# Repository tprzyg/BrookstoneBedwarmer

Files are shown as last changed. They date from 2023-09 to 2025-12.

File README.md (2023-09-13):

# Brookstone Bedwarmer / Heated Mattress Pad Controller.

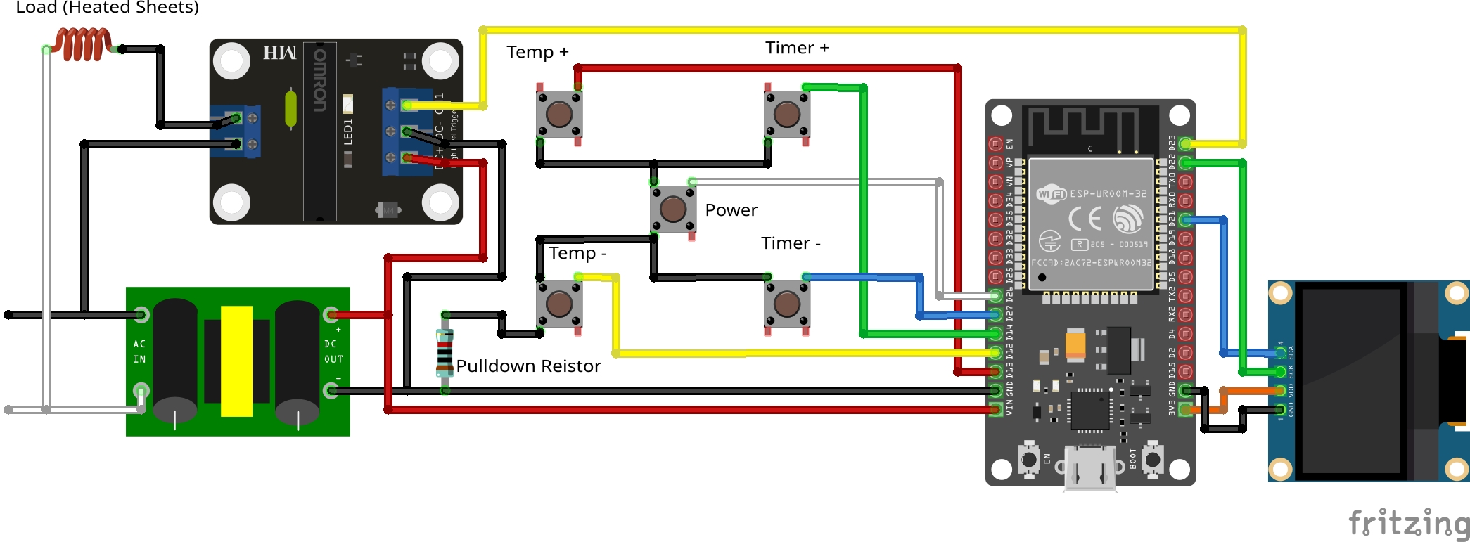
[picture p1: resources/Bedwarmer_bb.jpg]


This was a project to replace a flaky controller for a Brookstone Bedwarmer / Heated Mattress Pad, purchased at Bed Bath and Beyond. The heated mattress pad worked well in the beginning in the US, but after moving to Japan it became very flaky (most likely not liking 100V/50Hz instead of 110V/60Hz).

I used ESP32 board with 0.96" OLED SSD1306 type display, a set of two solid state relays (for controlling the A/C power), a small 5V PSU board and a 2A fuse with a housing. Below are links to the products on Japanese Amazon site (I'm sure that some similar/comparable products exist on your local Amazon or at some local electronics parts store).
- ESP32 DevKit boards: https://amzn.asia/d/9b7Ar7T
- 5V power modules: https://amzn.asia/d/gfirg1F
- Glass tube fuses and inline housings: https://amzn.asia/d/3iPEoGX
- Solid State Relays: https://amzn.asia/d/8DtwuSe
- 0.96" OLED Displays: https://amzn.asia/d/c7P6Bzr

This project could work with some modifications using ESP8266 board as well (I just happened to have extra ESP32 and no ESP8266 on hand).

Wiring the OLED screen is using I2C specific pins on ESP32 as SDA (GPIO_21) and SCL (GPIO_22) - these will be different when using ESP8266!
Also, the OLED screen uses 3.3V, so it is wired to the 3.3V output on ESP32 rather than using separate 3.3V regulator board.
I reused housing and most of the board of the original Brookstone controller (but desoldered most of the components - leaving only buttons/switches on the board).
I masked the display window with black electrical tape (as the 0.96" OLED is slightly smaller than the original segmented LCD - about2mm (about 0.08 in) on each side of the screen is masked). The OLED is (unprofessionally) mounted to the housing with the same black electrical tape. I also used copious amounts of electrical tape to cover the original board, to prevent any prospects of something touching PCB and shorting.
I checked carefully which wire brings "live" A/C and which is neutral and connected the bedwarmer heating element with a fuse on that line, to make sure that if anything electrical malfunction happens there is no "live" current in the bedwarmer / mattress pad.
I also slightly changed the behavior of the controller. The original controller default timer setting was 10hrs with adjustments by 30min up/down and the timer restarted every timer the timer+ or timer- buttons were pressed. My implementation uses a default 3 hrs. timer and with timer+/timer- you can increase or decrease the runtime in 10min steps, without restarting the timer.
The display also shows the remaining time on the timer, rather than the timer setting.

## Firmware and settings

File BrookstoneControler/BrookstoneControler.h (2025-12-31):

#define MIN_TEMP 1
#define MAX_TEMP 99
#define TEMP_STEP 1
#define DEFAULT_TEMP 25
#define MIN_DUTY_CYCLE 0
#define MAX_DUTY_CYCLE 1
#define HEATER_TIME_CYCLE 2000

#define TIMER_STEP 1
#define MIN_TIMER TIMER_STEP
#define MAX_TIMER 720
#define DEFAULT_TIMER 180

#define MIN_DELAY_TIME 180
#define MIN_BUTTON_PRESS_TIME 200

// Define PINs for buttons,
#define TEMP_PLUS_PIN GPIO_NUM_13
#define TEMP_MINUS_PIN GPIO_NUM_12
#define TIMER_PLUS_PIN GPIO_NUM_14
#define TIMER_MINUS_PIN GPIO_NUM_27
#define POWER_ON_PIN GPIO_NUM_26
#define HEATER_RELAY_PIN GPIO_NUM_25

// Settings for the 0.96" SSD1306 OLED SCREEN
#define SCREEN_I2C 0x3C
#define SCREEN_WIDTH 128
#define SCREEN_HEIGHT 64
#define DISPLAY_DIMMING 15000
#define DISPLAY_TIMEOUT 60000
#define DISPLAY_REFRESH_RATE 500

#define DEBUG_LEVEL 1

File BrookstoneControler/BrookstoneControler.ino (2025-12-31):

/*
 * Brookstone Bedwarmer replacement controller.
 * (C)2022 Tomasz Przygoda <tprzyg@yahoo.com>
 *
 * 4 input buttons (reused from the original controller board) for temp+, temp-, timer+ and timer-
 * 1 Power on/off button (also reused from the original board) with display ON it will set the ESP32 into deep sleep
 * The original segmented LCD display was replaced with 0.96" OLED (SSD1306)
 * Temperature is adjusted from 10% to 100% with 10% increments
 * Timer can be adjusted from 1min to 12hrs (originally was from 30min to 8hrs)
 * Logic was changed to allow for 1min timer-step value (originally 30min step value)
 * and also the display will show not the preset timer value, but rather the remaining hours:minutes
 * Display will dim after 15 seconds and go blank after 60 seconds of inactivity
 * When display is inactive, pressing any button (including power button) will reactivate the display
 * When display is active pressing adjustment buttons will make the desired adjustment
 * while pressing power button will turn off heat, reset timer and put the controller into deep sleep
 * When controller is in deep sleep mode, pressing power button will restart and re-initialize the controller,
 * but all other buttons are ignored
 * When timer runs out, the controller will turn off heat, reset timer and put the controller into deep sleep
 */

#include <Wire.h>
#include <Adafruit_GFX.h>
#include <Adafruit_SSD1306.h>
#include <Fonts/FreeSans9pt7b.h>
#include <Fonts/FreeSans12pt7b.h>
#include <Fonts/FreeSans18pt7b.h>
#include <Fonts/FreeSans24pt7b.h>
#include <Fonts/FreeSansBold9pt7b.h>
#include <Fonts/FreeSansBold12pt7b.h>
#include <Fonts/FreeSansBold18pt7b.h>
#include <Fonts/FreeSansBold24pt7b.h>

#include "BrookstoneControler.h"
#include "Button.h"

// Allocate the SSD1306 OLED Screen
Adafruit_SSD1306 display(SCREEN_WIDTH, SCREEN_HEIGHT, &Wire, -1);


bool wifiOn;
bool timerOn;
bool heaterOn;
bool displayOn;
bool refreshDisplay;
bool enterSleepMode;

unsigned int heatSetting;
unsigned int lastButtonPressed;

unsigned long currentTime;
unsigned long timerEndTime = 0;
unsigned long timerStartTime = 0;
unsigned long timerRemaining = 0;

unsigned long lastDisplayOn = 0;
unsigned long lastDisplayUpdateTime = 0;

unsigned long currentPressTime = 0;
unsigned long lastButtonPressTime = 0;
unsigned long lastButtonActionTime = 0;

unsigned long lastHeatOnTime = 0;
unsigned long lastHeatOffTime = 0;

typedef void (*dummyFunction)(void);

void updateHeatSetting(unsigned int myFactor) {
  currentPressTime = millis();
  refreshDisplay = true;
  unsigned int newHeatSetting = heatSetting + TEMP_STEP * myFactor;

  if ((newHeatSetting <= MAX_TEMP) and (newHeatSetting >= MIN_TEMP)) {
    heatSetting = newHeatSetting;
    lastButtonActionTime = currentPressTime;
  }
}

void updateTimerSetting(unsigned int myFactor) {
  currentPressTime = millis();
  refreshDisplay = true;
  unsigned long newTimerEndTime = timerEndTime + (TIMER_STEP * myFactor) * 60000;

  if (((newTimerEndTime - currentTime )<= MAX_TIMER * 60000) and ((newTimerEndTime - currentTime) >= MIN_TIMER * 60000)) {
    timerEndTime = newTimerEndTime;
    lastButtonActionTime = currentPressTime;
  }
}

void IRAM_ATTR temp_up_ISR() {
  currentPressTime = millis();
  if (currentPressTime - lastButtonPressTime > MIN_BUTTON_PRESS_TIME) {
    lastButtonPressTime = currentPressTime;
    if (displayOn) {
      lastButtonPressed = TEMP_PLUS_PIN;
    } else {
      displayOn = true;
      lastDisplayOn = currentPressTime;
    }
  }
}

void IRAM_ATTR temp_down_ISR() {
  currentPressTime = millis();
  if (currentPressTime - lastButtonPressTime > MIN_BUTTON_PRESS_TIME) {
    lastButtonPressTime = currentPressTime;
    if (displayOn) {
      lastButtonPressed = TEMP_MINUS_PIN;
    } else {
      displayOn = true;
      lastDisplayOn = currentPressTime;
    }
  }
}

void IRAM_ATTR timer_up_ISR() {
  currentPressTime = millis();
  if (currentPressTime - lastButtonPressTime > MIN_BUTTON_PRESS_TIME) {
    lastButtonPressTime = currentPressTime;
    if (displayOn) {
      lastButtonPressed = TIMER_PLUS_PIN;
    } else {
      displayOn = true;
      lastDisplayOn = currentPressTime;
    }
  }
}

void IRAM_ATTR timer_down_ISR() {
  currentPressTime = millis();
  if (currentPressTime - lastButtonPressTime > MIN_BUTTON_PRESS_TIME) {
    lastButtonPressTime = currentPressTime;
    if (displayOn) {
      lastButtonPressed = TIMER_MINUS_PIN;
    } else {
      displayOn = true;
      lastDisplayOn = currentPressTime;
    }
  }
}

void IRAM_ATTR power_button_ISR() {
  currentPressTime = millis();
  if (currentPressTime - lastButtonPressTime > MIN_BUTTON_PRESS_TIME) {
    refreshDisplay = true;
    lastButtonPressTime = currentPressTime;
    if (displayOn) {
      lastButtonPressed = POWER_ON_PIN;
      enterSleepMode = true;
    } else {
      displayOn = true;
      lastDisplayOn = currentPressTime;
    }
  }
}

void checkPowerOff() {
  currentTime = millis();
  if (enterSleepMode) {
    Serial.println("Preparing for DEEP_SLEEP mode...");
    if (digitalRead(HEATER_RELAY_PIN) == HIGH) {
      Serial.print("Turning Heater OFF @ ");
      Serial.println(currentTime);
      digitalWrite(HEATER_RELAY_PIN, LOW);
    }
    Serial.println("Turning timer OFF");
    heatSetting = 0;
    timerEndTime = 0;
    timerStartTime = 0;
    timerRemaining = 0;
    Serial.println("Turning display OFF");
    display.clearDisplay();
    display.display();
    display.ssd1306_command(SSD1306_DISPLAYOFF);
    Serial.print("Setting up RTC_WKAEUP on ");
    Serial.print(POWER_ON_PIN);
    Serial.println(" to become a wakeup button");
    esp_sleep_enable_ext0_wakeup(POWER_ON_PIN, 0);
    Serial.println("Entering DEEP_SLEEP mode.");
    delay(1000);
    esp_deep_sleep_start();
  }
}

void updateDisplay() {
  currentTime = millis();
  if (displayOn) {
    if (currentTime - lastDisplayUpdateTime >= DISPLAY_REFRESH_RATE) {
      refreshDisplay = true;
    }
  }
  if (refreshDisplay) {
    lastDisplayUpdateTime = currentTime;
    int timerHours = timerRemaining / 60;
    int timerMinutes = timerRemaining - timerHours * 60;
    char heatStr[8];
    sprintf(heatStr, "%3d%%", heatSetting);
    char timeStr[8];
    sprintf(timeStr, "%2d:%02d", timerHours, timerMinutes);
    if (currentTime - lastDisplayOn > DISPLAY_DIMMING) {
      displayOn = true;
      // PUT DISPLAY DIMMING CODE HERE
    }
    if (currentTime - lastDisplayOn > DISPLAY_TIMEOUT) {
      displayOn = false;
      display.ssd1306_command(SSD1306_DISPLAYOFF);
    }
    if (displayOn) {
      // MAKE SURE DISPLAY IS ON
      display.ssd1306_command(SSD1306_DISPLAYON);
      display.clearDisplay();
      display.setTextColor(WHITE);
      display.setFont(&FreeSans9pt7b);
      display.setTextSize(1);
      display.setCursor(0, 24);
      display.println("Heat:");
      display.setFont(&FreeSansBold12pt7b);
      display.setTextSize(1);
      display.println(heatStr);
      display.setFont(&FreeSans9pt7b);
      display.setTextSize(1);
      display.setCursor(0, 80);
      display.println("Timer:");
      display.setFont(&FreeSansBold12pt7b);
      display.setTextSize(1);
      display.println(timeStr);
      display.display();
    }
    refreshDisplay = false;
    if (DEBUG_LEVEL > 0) {
      Serial.print("LastDisplayOn = ");
      Serial.print((currentTime-lastDisplayOn)/1000);
      Serial.print("s ago, Heat = ");
      Serial.print(heatStr);
      Serial.print(", Timer = ");
      Serial.println(timeStr);
    }
  }
}

void checkTimerOff() {
  currentTime = millis();
  long timerRemainingMillis = timerEndTime - currentTime;
  if (timerRemainingMillis > 60000) {
    timerRemaining = round(timerRemainingMillis / 60000);
  } else {
    timerRemaining = 0;
    timerOn = false;
  }
  if (!timerOn) {
    timerEndTime = 0;
    timerStartTime = 0;
    timerRemaining = 0;
    timerOn = false;
    heaterOn = false;
    enterSleepMode = true;
  }
}

void runHeater() {
  currentTime = millis();
  if (timerOn) {
    unsigned long dutyOnTime = round(HEATER_TIME_CYCLE * (heatSetting * 0.01 * (MAX_DUTY_CYCLE - MIN_DUTY_CYCLE) + MIN_DUTY_CYCLE));
    unsigned long dutyOffTime = HEATER_TIME_CYCLE - dutyOnTime;
    if ((heatSetting >= MIN_TEMP) and (heatSetting <= MAX_TEMP)) {
      if (!heaterOn) {
        if (currentTime - lastHeatOffTime >= dutyOffTime) {
          // TURN THE HEAT ON
          digitalWrite(HEATER_RELAY_PIN, HIGH);
          if (DEBUG_LEVEL > 0) {
            Serial.print("Heater ON after ");
            Serial.println(currentTime - lastHeatOffTime);
          }
          heaterOn = true;
          lastHeatOnTime = currentTime;
        }
      } else {
        if (currentTime - lastHeatOnTime >= dutyOnTime) {
          // TURN THE HEAT OFF
          digitalWrite(HEATER_RELAY_PIN, LOW);
          if (DEBUG_LEVEL > 0) {
            Serial.print("Heater OFF after ");
            Serial.println(currentTime - lastHeatOnTime);
          }
          heaterOn = false;
          lastHeatOffTime = currentTime;
        }
      }
    } else {
      Serial.println("Invalid heat setting... ignoring...");
      // MAKE SURE THAT THE HEAT IS OFF
      if (digitalRead(HEATER_RELAY_PIN) == HIGH) {
        digitalWrite(HEATER_RELAY_PIN, LOW);
      }
    }
  }
}

void checkButtons() {
  currentTime = millis();
  bool buttonAction = false;
  unsigned int actionFactor = 1;
  if (digitalRead(lastButtonPressed) == LOW) {
    if (currentTime - lastButtonPressTime > 10 * MIN_BUTTON_PRESS_TIME) {
      buttonAction = true;
      actionFactor = 10;
    } else if (currentTime - lastButtonPressTime > 5 * MIN_BUTTON_PRESS_TIME) {
      buttonAction = true;
      actionFactor = 5;
    } else if (currentTime - lastButtonActionTime > MIN_BUTTON_PRESS_TIME) {
      buttonAction = true;
    }
  }
  if (currentTime - lastButtonActionTime < round(2*MIN_BUTTON_PRESS_TIME / actionFactor)) {
    buttonAction = false;
  }
  if (buttonAction) {
    lastButtonActionTime = currentTime;
    switch (lastButtonPressed) {
      case TEMP_PLUS_PIN:
       updateHeatSetting(1);
       break;
      case TEMP_MINUS_PIN:
       updateHeatSetting(-1);
       break;
      case TIMER_PLUS_PIN:
       updateTimerSetting(1);
       break;
      case TIMER_MINUS_PIN:
       updateTimerSetting(-1);
       break;
    }
  }
}

void setup_pin(unsigned int PIN, dummyFunction ISR_routine) {
  pinMode(PIN, INPUT_PULLUP);
  attachInterrupt(PIN, ISR_routine, FALLING);
}

void setup() {
  // Setup Serial Monitor
  Serial.begin(115200);
  // Initialize the SSD1306 OLED Screen
  if (!display.begin(SSD1306_SWITCHCAPVCC, SCREEN_I2C)) {
    Serial.println(F("SSD1306 allocation failed"));
    delay(10000);
    ESP.restart();
  }
  delay(2000);
  display.ssd1306_command(SSD1306_DISPLAYON);
  display.clearDisplay();
  display.setRotation(1);
  display.setTextColor(WHITE);
  display.setFont(&FreeSans9pt7b);
  display.setTextSize(1);
  display.clearDisplay();
  display.display();
  Serial.println("ESP32 Controller for a Brookstone Heated Mattress Pad.");
  timerOn = true;
  heaterOn = false;
  displayOn = true;
  refreshDisplay = true;
  enterSleepMode = false;
  heatSetting = DEFAULT_TEMP;
  lastDisplayOn = currentTime;
  timerStartTime = currentTime;
  timerRemaining = DEFAULT_TIMER;
  timerEndTime = timerStartTime + DEFAULT_TIMER * 60000;
  lastButtonPressTime = currentTime;
  setup_pin(POWER_ON_PIN, power_button_ISR);
  setup_pin(TEMP_PLUS_PIN, temp_up_ISR);
  setup_pin(TEMP_MINUS_PIN, temp_down_ISR);
  setup_pin(TIMER_PLUS_PIN, timer_up_ISR);
  setup_pin(TIMER_MINUS_PIN, timer_down_ISR);
  pinMode(HEATER_RELAY_PIN, OUTPUT);
  display.println("ON");
  display.display();
  updateDisplay();
}

void loop() {
  checkButtons();
  checkTimerOff();
  checkPowerOff();
  updateDisplay();
  runHeater();
}

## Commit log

2022-12-31 adding initial version of the controller sketch - there are some bugs to fix, before fully working
    [BrookstoneControler.ino]
2022-12-31 Update BrookstoneControler.ino
    started to refactor to use timerRemaining minutes rather than the convoluted timerSetting and calculating remaining on the fly (which sometimes ended up with timerRemaining going negative).
2022-12-31 adding include file for predefined macros, and finished updating the refactored code - it compiles, but not tested fuctionality, so bug maybe present
    [BrookstoneControler.h, BrookstoneControler.ino]
2022-12-31 fixing timerEndTime initialization missing
    [BrookstoneControler.ino]
2022-12-31 fixed displayRefresh instead of refreshDisplay and added calculation of timerRemaining
    [BrookstoneControler.ino]
2022-12-31 fixed minor bugs around temp+/temp- logic, and also refreshDisplay interval with no buttons pressed.
    [BrookstoneControler.ino]
2023-01-01 added functionality to read short and long button presses (for temp+/- and timer+/-)
    [BrookstoneControler.h, BrookstoneControler.ino]
2023-01-02 slight rework of button long press routine and added wifi connection (through WiFi Manager)
    [BrookstoneControler.h, BrookstoneControler.ino]
2023-01-23 rename src
    renaming src to BrookstoneController so that I can run Arduino IDE directly from the directory
2023-01-23 .gitignore
    added .gitignore and selections for files to ignore from Arduino IDE
2023-09-12 Adding Fritzing stuff (wiring image, example board design, etc)
    [Bedwarmer.fzz]
2023-09-12 Updated Fritzing file and exports
    [Bedwarmer.fzz]
2023-09-13 JPEG of wiring diagram (exported from Fritzing)
2023-09-15 removing pcb pdf files and updating jpg and fzz to latest version
    [Bedwarmer.fzz]
2023-09-15 another update of the Fritzing file and exported JPEG
    [Bedwarmer.fzz]
2024-01-15 Update BrookstoneControler.ino
    Fixed my name :)
    [BrookstoneControler.ino]
2025-06-06 Updated button logic to allow 1min timer changes and button short/long press, updated the order of screen init to limit showing garbage on the screen
    [BrookstoneControler.h, BrookstoneControler.ino]
2025-06-06 adding Button and Relay header files and library files
2025-06-06 fixed missing HEATER_RELAY_PIN initialization
    [BrookstoneControler.ino]
2025-12-22 Fixed the bug, where any button press during display sleep, other than power button, would not only wake display from sleep, but also perform action (eg. timer or heat increase/decrease
    [BrookstoneControler.ino]
2025-12-31 simplified the timer up/down and heat up/down functions, fixed the waking up display from sleep, without taking button assigned actions, changed heat setting to use 1% increments, and generally clean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
    [BrookstoneControler.h, BrookstoneControler.ino, Button.h]
2025-12-31 fixed the OOB files for Button and Relay class (these are work-in-progress)
    [BrookstoneControler.ino]
